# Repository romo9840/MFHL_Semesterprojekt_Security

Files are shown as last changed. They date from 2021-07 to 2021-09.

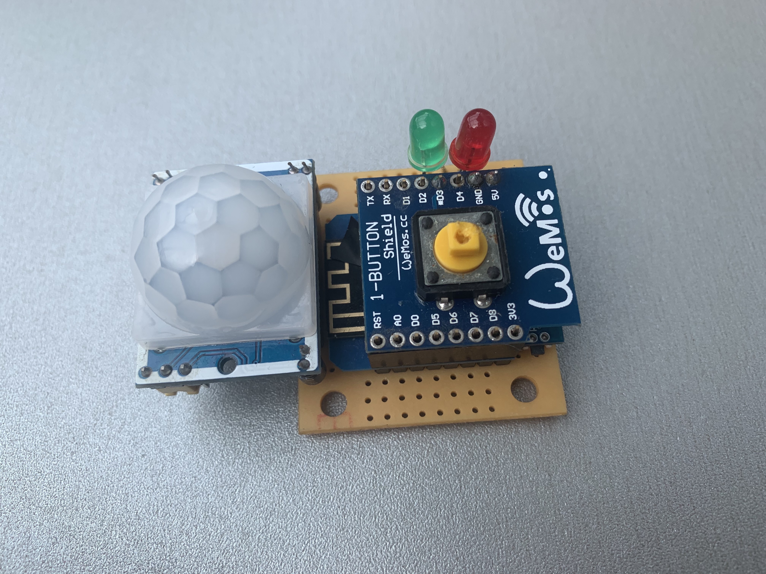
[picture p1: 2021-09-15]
Pictures/11.09_bare_other_side.jpg

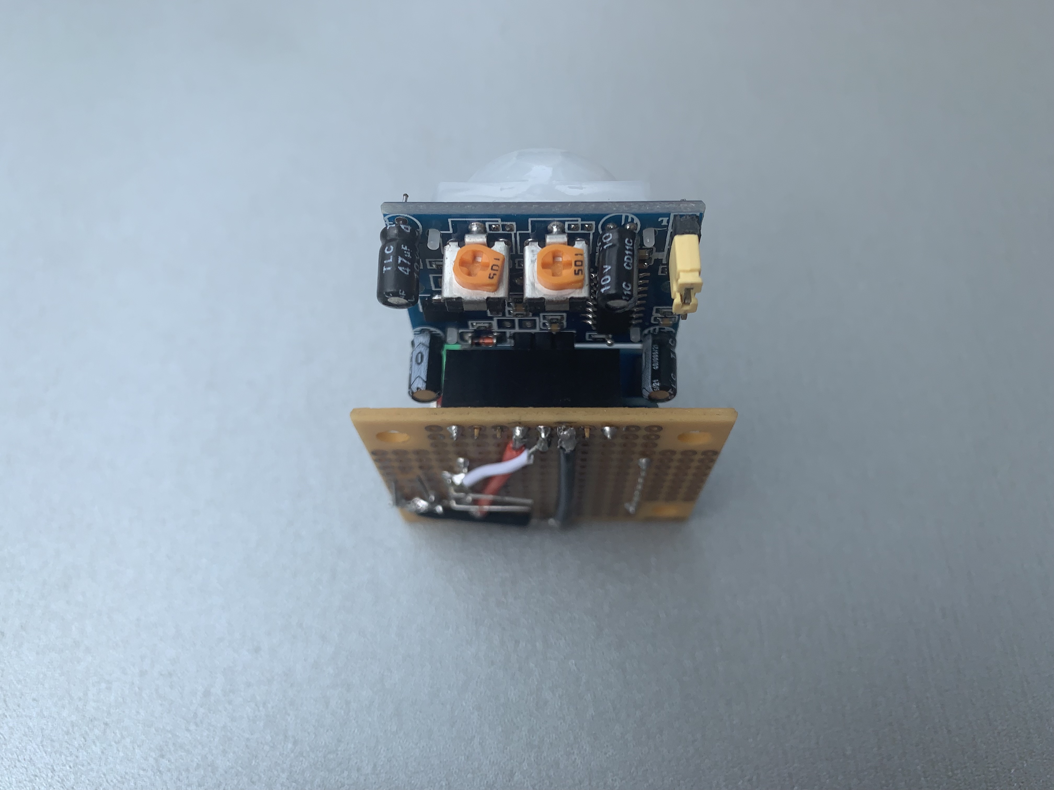
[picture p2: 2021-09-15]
Pictures/11.09_bare_back2.jpg

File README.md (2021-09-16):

# MFHL_Semesterprojekt_Security

Das hierzusehende Projekt dient dazu eine sehr einfache Sicherheitsanlage zu erschaffen. 

Collaborators: Marvin Timmerman, Felix Büntemeier, Hendrik Nessen & Leif Meyer

Hardware:
  * ESP8266 Lolin Wemos D1 Mini 
  * ~~2 Buttons~~ ESP8266 Button Shield
  * Zwei LEDs 5mm (Rot und Grün)
  * 1 Widerstand 330 Ohm 
  * Ein PIR Bewegungssensor
  * Ein Netzteil
  
  ~~Möglicherweise mit Battery:~~
   * ~~1 D1 Mini Battery Shield~~
   * ~~1 LiPo Battery~~

Software:
 * Arduino 
 * Node-RED
  
Das Sicherheitssystem muss über einen "Home" sowie "Away" Zustand verfügen.
Den Zugang zu diesen Zuständen erreicht man durch das Betätigen des integrierten Buttons.

Nach einmaligem Betätigen des Buttons wird der Zustand "Away" erreicht.
  * Die grüne LED erlischt und die rote LED permanent auf.
  * Der Timer beginnt und stoppt bei einer Dauer von 2 Minuten.
  * Nachdem der Timer abgelaufen ist, erfasst der Sensor jede Bewegung.
  * Nachdem eine Bewegung erkannt wurde, wird umgehend eine Benachrichtung an Discord sowie Email versandt.
  * Innerhalb der Zustände kann ein Wechsel ausnahmslos durch Betätigen des Buttons initiiert werden.

Das Sicherheitssystem wird im "Home" Zustand lediglich in Bereitsschaft versetzt. Hier wird nur das auf Betätigen des Buttons reagiert.
 * Die grüne LED leuchtet permanent auf.

Nach längeren Betätigung des Buttons wird der Nachtmodus aufgerufen. Dabei erlöscht die aktuelle LED.

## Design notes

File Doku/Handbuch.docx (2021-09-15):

Handbuch „Sicherheitssystem“

Inbetriebnahme:

1. Vorbereitung
  a. Arduino Code von https://github.com/romo9840/MFHL_Semesterprojekt_Security/tree/main/Software/Arduino/Securitysystem herunterladen
  b. Bibliotheken für Arduino und Paletten für Node Red einbinden
    i. Paletten: node-red-contrib-discord-advanced, node-red-node-email
    ii. Bibliotheken: https://pubsubclient.knolleary.net, https://github.com/esp8266/Arduino/tree/master/libraries/ESP8266WiFi
  c. Verbindung zwischen Box und Computer mittels Micro-USB-Kabel herstellen
  d. WiFi-Daten und MQTT-Broker anpassen (Bilder)

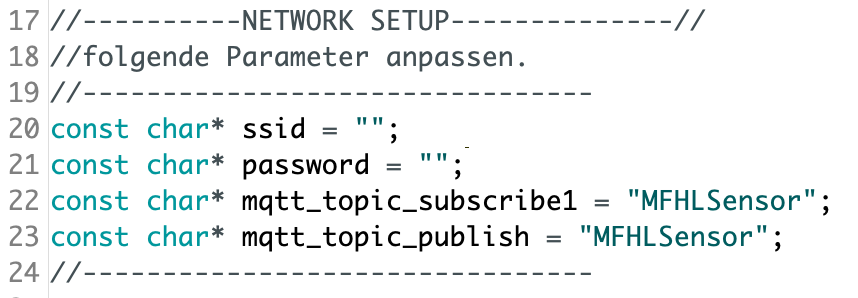
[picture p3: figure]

  e. Software auf die Security Box laden
2. Installation und Bedienung
  a. Schließen Sie das Sicherheitssystem mit dem im Lieferumfang enthaltenen Micro-USB Kabel an das Stromnetz an, um die Inbetriebnahme zu starten.
  b. Sobald das Sicherheitssystem mit dem Strom verbunden wurde, leuchtet die grüne LED auf.
  c. Das Sicherheitssystem befindet sich nun im „Home-Modus“.
  d. Durch das Betätigen des Home-Buttons wird der „Away-Modus“ aktiviert.
  e. Die rote LED leuchtet auf. Das Wechseln der Modi ist jederzeit durch Betätigen des Home-Buttons möglich.
  f. Das Sicherheitssystem ist nun einsatzbereit.
3. Installation des Benachrichtigungssystems
  a. 2.1 Email-Benachrichtigung
    i. Um vom Benachrichtigungssystem entsprechende Warnmeldungen zu erhalten, muss eine Verbindung zum Email- sowie Discord-Server hergestellt werden.

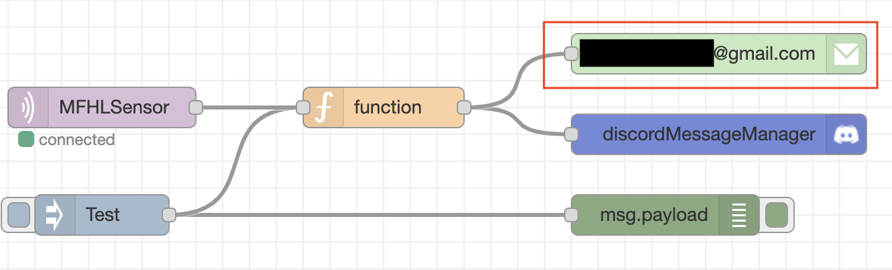
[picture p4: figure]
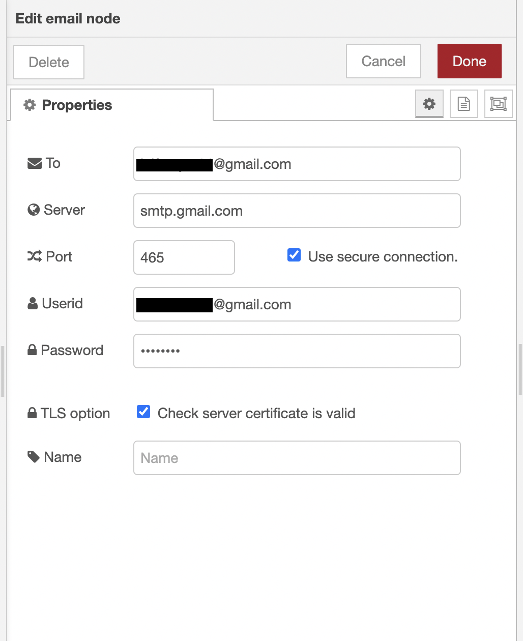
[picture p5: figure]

    ii. Verwenden sie die Email-App ihres Mobiltelefons oder eines Heimrechners um Ihre Wunschadresse für eine Benachrichtigung zu versenden
  b. 2.2 Discord-Benachrichtigung (wenn gewünscht):
    i. Um sich mit dem Sicherheitsserver zu verbinden, laden Sie die benötigte Software „Discord“ unter der Webseite (www.Discord.de) herunter.
    ii. Nach erfolgreicher Installation können Sie den Sicherheitsserver hinzufügen, indem sie auf die Schaltfläche „Server hinzufügen“ klicken.
    iii. Navigieren Sie anschließend zu der Schaltfläche „Tritt einem Server bei“.
    iv. Nach Eingabe des Einladungslinks (abcdef.ff.f) betreten Sie den Sicherheitsserver.
    v. Das Benachrichtigungssystem ist nun einsatzbereit.

Home-Modus: In diesem Zustand reagiert das Sicherheitssystem auf keine Bewegung.

Vorzugsweise sollte dieser Modus aktiviert werden, wenn Sie sich zu Hause befinden.

BILD

Away-Modus: Nach einer Sicherheitsdauer von 2 Minuten wird die Bewegungserfassung des Sicherheitssystems aktiviert.

Sollte das Sicherheitssystem eine Bewegung erkennen, wird eine Warnmeldung durch das Benachrichtigungssystem eingeleitet.

BILD

Known-Issues:

Interne LED des Wemos D1 mini wird über PIN D4 gesteuert, deswegen kann diese auch leuchten

Videomaterial zur Inbetriebnahme:

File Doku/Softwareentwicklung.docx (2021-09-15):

Beschreibung der Systemarchitektur und der Softwareentwicklung

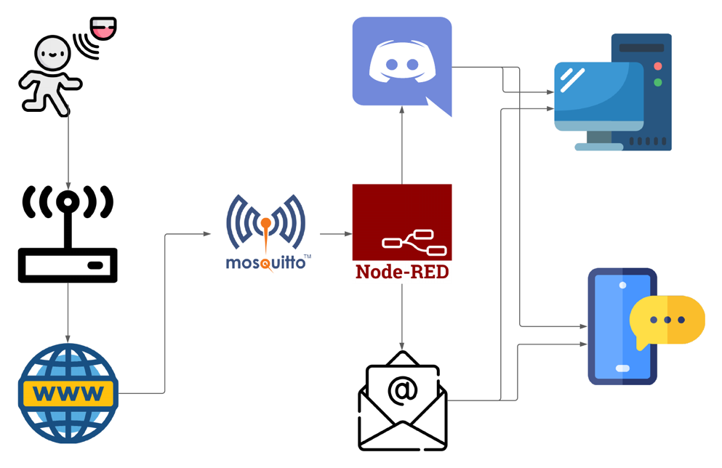
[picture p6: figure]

Abbildung 1/ Systemübersicht

Das Sicherheitssystem stellt bei Inbetriebnahme eine Verbindung zu einem spezifizierten Netzwerk her. Dies ist notwendig, um eine Kommunikation zwischen den Systemen zu gewährleisten. Erkennt das Sicherheitssystem eine Bewegung, wird eine entsprechende Meldung via MQTT über das Internet übermittelt. Die Daten werden von einem Broker (Mosquitto) empfangen und an einen Node-RED Server weitergeleitet.

Die empfangenen Daten werden mittels Node-RED als Email-, sowie Discord-Nachricht verarbeitet und weitergeleitet. Die verarbeitete Meldung erscheint schließlich auf den jeweiligen Endgeräten.

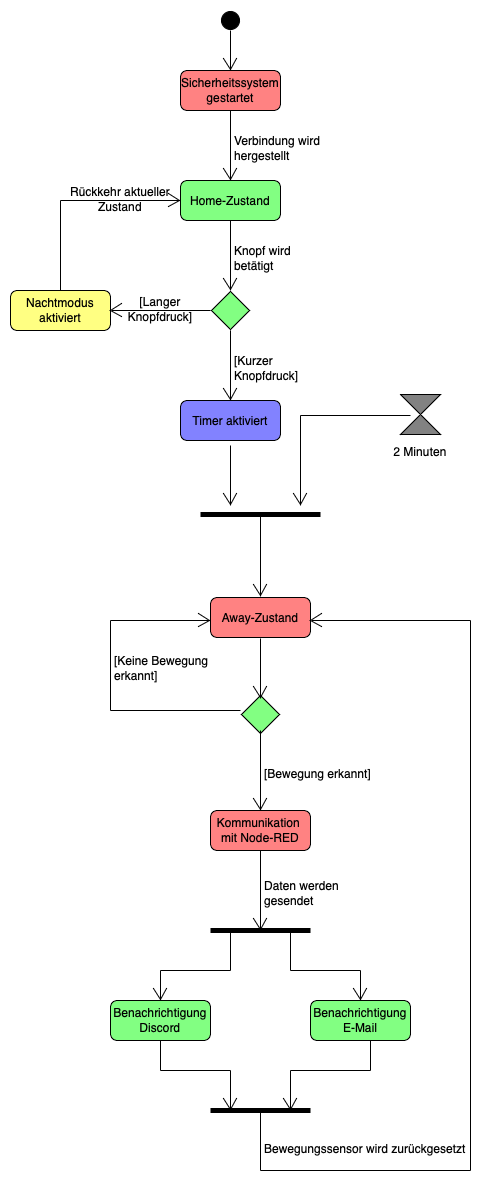
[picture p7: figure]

Abbildung2/ Zustandsdiagramm

Bei Start des Sicherheitssystems wird beginnend das Setup des Programms ausgeführt. In dieser Phase werden Verbindungen zum Netzwerk, zum MQTT-Broker sowie zum Node-RED Client hergestellt und aufrechterhalten.

Nachdem alle Verbindungen erfolgreich hergestellt werden konnten, beginnt die „Loop-Methode“ des Programms. In diesem Teil des Programms wird die Logik des Buttons und des Sicherheitssystems umgesetzt.

Die von Spivey entwickelte Button-Logik nutzt Zustände und Timer, um zwischen kurzen und langen Tastendrücken zu unterscheiden. Dies ist für die spezifische Funktionalität des Sicherheitssystems notwendig. Erkennt das System einen kurzen Knopfdruck, wechselt das System abhängig vom vorherigen Zustand in den „Home“- oder den „Away“-Zustand. Registriert das System einen langen Knopfdruck, wird der Nachtmodus des Sicherheitssystems aktiviert. Die LED-Leuchten werden deaktiviert und der aktuelle Zustand bleibt bestehen.

Das eingeschaltete System befindet sich im Ausgangszustand „Home“. In diesem Zustand wird lediglich die grüne LED-Leuchte aktiviert. Es werden in diesem Zustand keine Bewegungsdaten erfasst und ausgewertet.

Nachdem das System in den „Away“ -Zustand gelangt, erlischt die grüne LED-Leuchte und die rote LED wird aktiviert. Mithilfe eines im Setup definierten Zählers „counter“, kann zwischen Zuständen vor und nach der Timerlogik separiert werden. Dabei wird bei erstmaligem Eintritt in den „Away“-Zustand durch den vordefinierten Zähler das Sicherheitszeitintervall von zwei Minuten gestartet. Nachdem der Timer abgelaufen ist, gelangt man durch das Inkrementieren des Zählers in den Folgezustand, welcher die Bewegungssensorik aktiviert.

Erkennt das Sicherheitssystem eine Bewegung, wird eine entsprechende Meldung an den MQTT-Broker übermittelt. Nach einer kurzen Verzögerung wird der Zähler wieder zurückgesetzt und das Programm gelangt wieder in den Zustand, welcher für die Bewegungserkennung verantwortlich ist. So kann eine Überwachung ohne erneute Einhaltung des Sicherheitszeitintervalls gewährleistet werden.

Die Datenübertragung wird über einen mit Node-RED eingerichteten Server abgewickelt. Innerhalb des Programms wird ein vordefiniertes Topic („MFHLSensor“) genutzt, um eine Kommunikation über den MQTT Broker zu ermöglichen. Bei eintretender Bewegungserkennung wird mit der „publishString“ Methode eine Kommunikation zwischen den Schnittstellen eingeleitet. Nachdem die Daten an Node-RED übermittelt worden sind, muss eine Weiterleitung an die entsprechenden Endgeräte stattfinden.

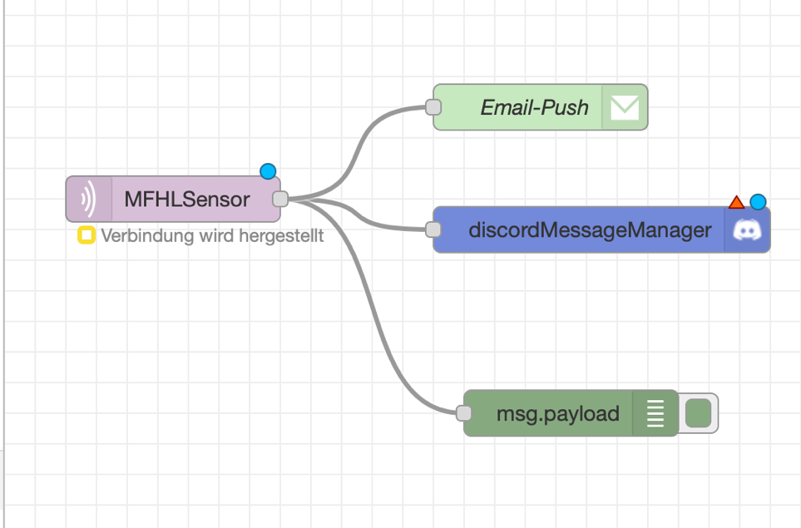
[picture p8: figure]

Abbildung 3/ Node-RED Konfiguration

Über das Netzwerk-Node „mqtt-in“ kann durch das Festlegen eines vorspezifizierten Servers, sowie Topics ein Dateninput verarbeitet werden. Dabei werden die Nodes „discord“ und „email“ zur Weiterleitung einer Push-Benachrichtigung genutzt.

Um eine Push-Benachrichtung an eine E-Mail Adresse weiterzuleiten, muss das „email“ Node lediglich mit Server, Port und den ID-Daten des Nutzers synchronisiert werden.

Um eine Push-Benachrichtigung via Discord-Bot durchzuführen, muss eine Applikation, sowie ein Discord-Bot initialisiert werden. Über das Developer-Portal von Discord kann eine entsprechende Applikation erstellt werden, welche das Verwenden eines Discord-Bots ermöglicht.

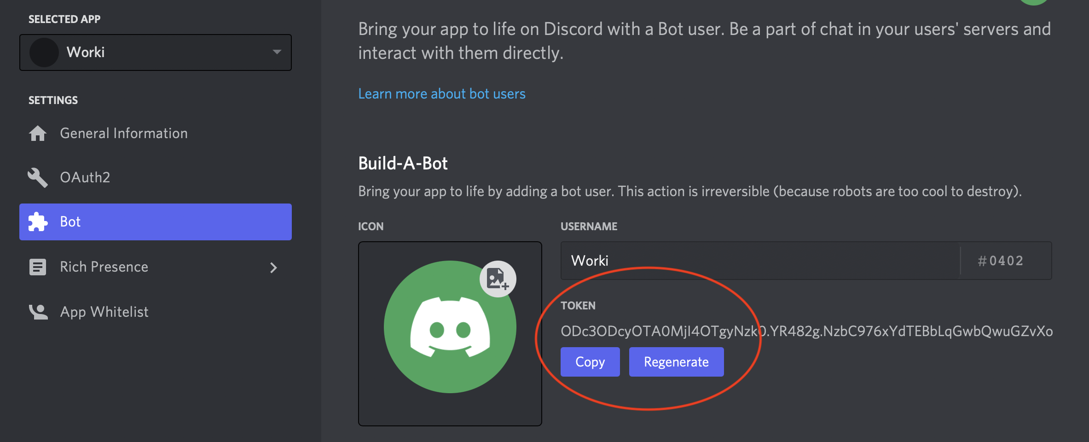
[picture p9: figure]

Abbildung 4/ Discord Developer Portal

Der erstellte Discord-Bot wird mit einem gegebenen Token über Node-RED initialisiert. So kann eine Kommunikation zwischen den Systemen stattfinden und eine Meldung an die Endgeräte weitergeleitet werden.

Code & Bibliotheken

Probleme bei der Software-Entwicklung:

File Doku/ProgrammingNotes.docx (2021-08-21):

# Node-Red Setup

### Email: ( node-red-node-email )

Um eine E-Mail mit Nodered zu verbinden ist es empfohlen eine gmail zu verwenden. Sonst ist es auch möglich andere E-mail Konten zu verbinden falls die entsprechenden Daten (Server, Port, Userid und Passwort) bekannt sind.

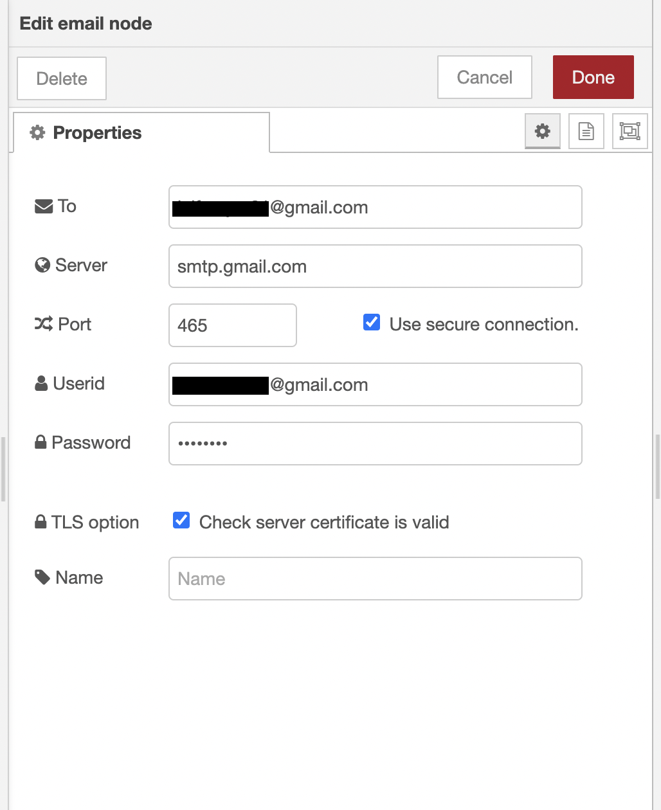
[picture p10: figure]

Hier ist die Dokumentation des Email-Nodes zu sehen:

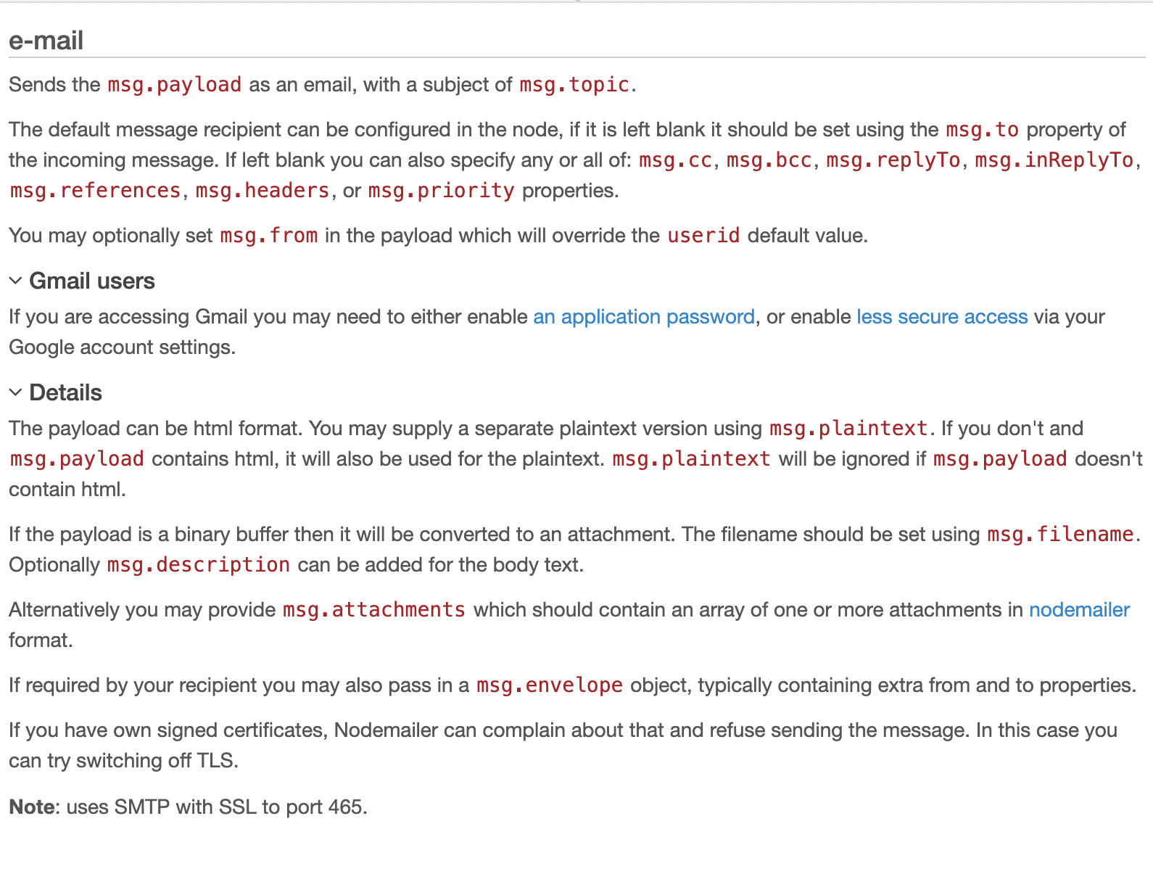
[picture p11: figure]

### Discord: ( node-red-contrib-discord-advanced )

Zuerst wird ein Discord-Bot erstellt. Dafür folgt man den folgenden Link, um die Discord Developer Seite zu erreichen https://discord.com/developers/applications. Nach den einloggen kann es sein, dass erneut den Link eingeben muss.

Zunächst ist eine Applikation sowie ein Bot in dieser Applikation zu erstellen. Dann muss der Bot mit einem Server verbunden werden. Der Bot wird mittels der OAuth2 Funktion einen Server ihrer Wahl zugewiesen (dafür muss aber ein Server schon erstellt sein). Die Attribute des Bots werden hier auch ausgesucht.

Hier wird als SCOPES:={bot} und BOT PERMISSIONS:={Send Messages} ausgewaehlt.

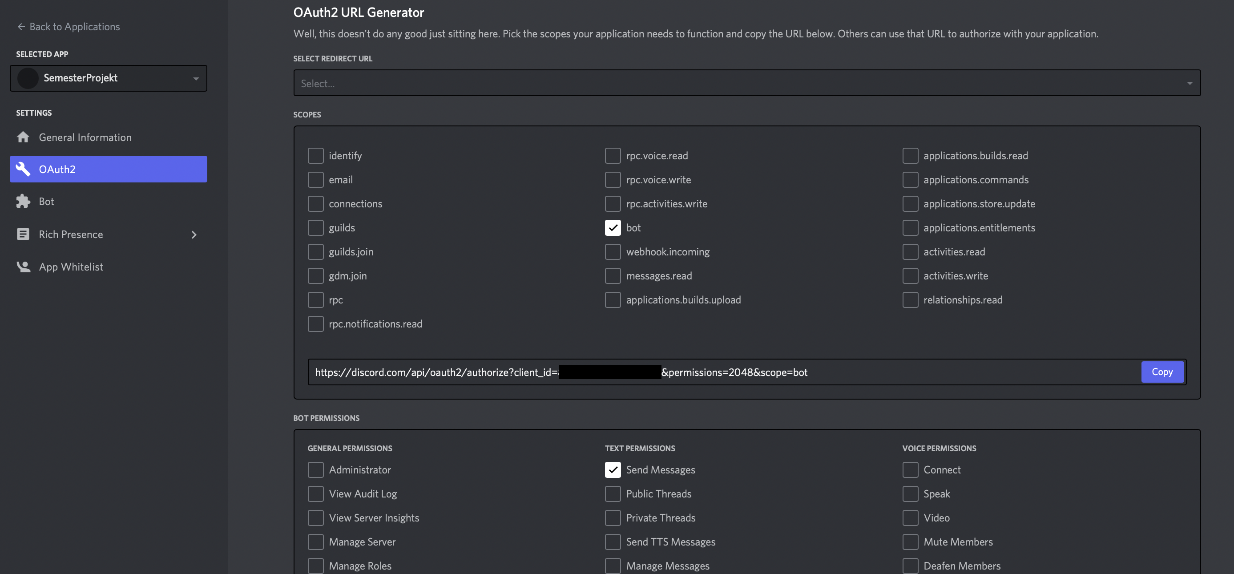
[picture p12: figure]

Der Link muss hier kopiert und in dem Browser eingefügt werden. Danach wird nach dem Server gefragt, der diesen Bot empfangen soll. Dies schließt das Setup von Discord aus ab.

#### Node Red:

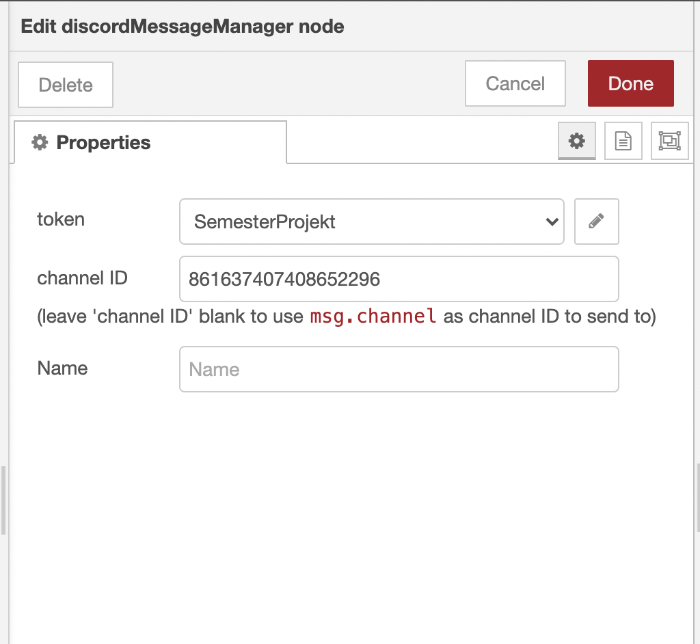
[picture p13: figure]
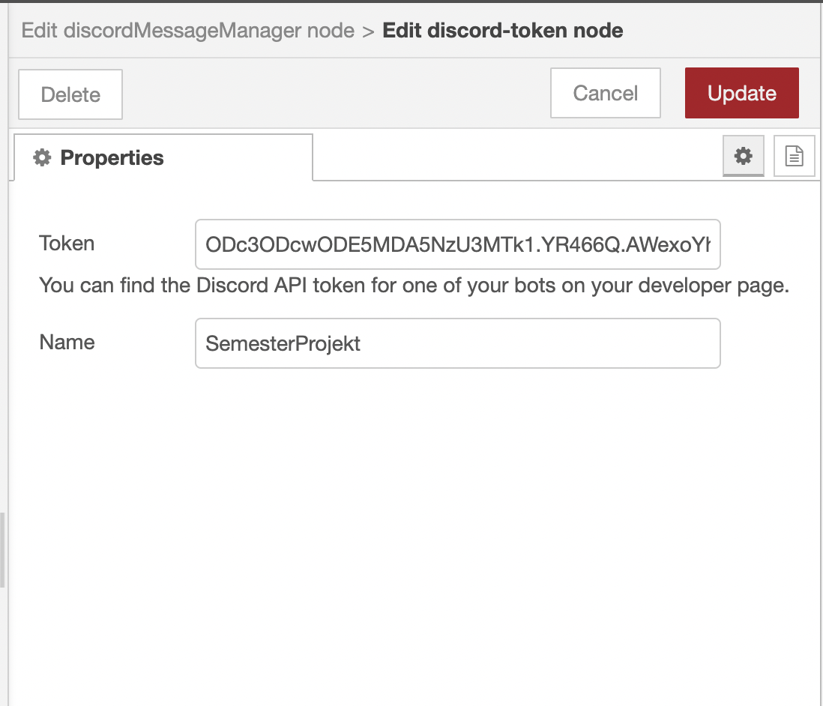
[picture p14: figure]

Die Channel_ID wird gefunden falls man in der Discord App

> Settings > App Settings > Advanced > Developer Mode enabled und dann beim Server die mit Rechtsklick auf die ID vom gewählten Channel kopiert.

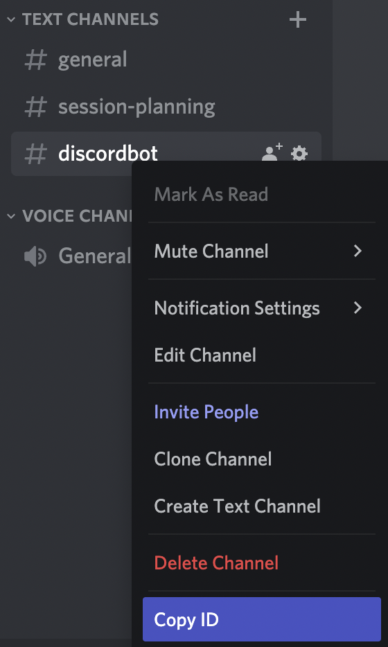
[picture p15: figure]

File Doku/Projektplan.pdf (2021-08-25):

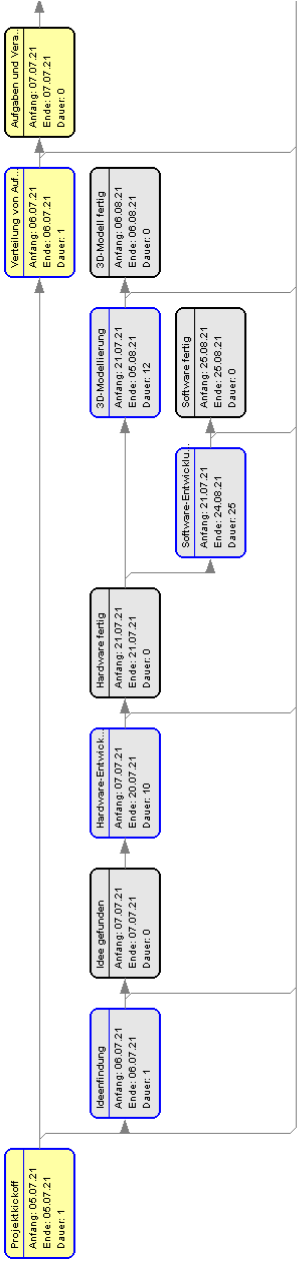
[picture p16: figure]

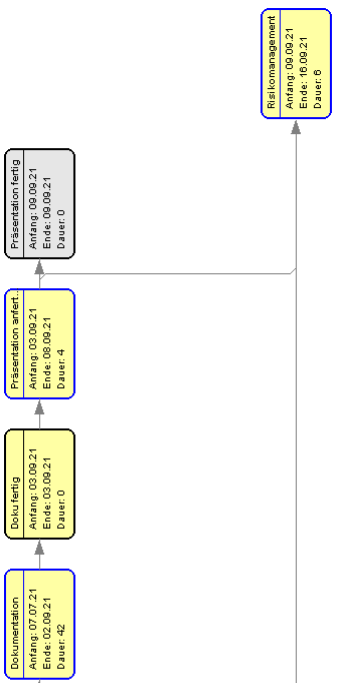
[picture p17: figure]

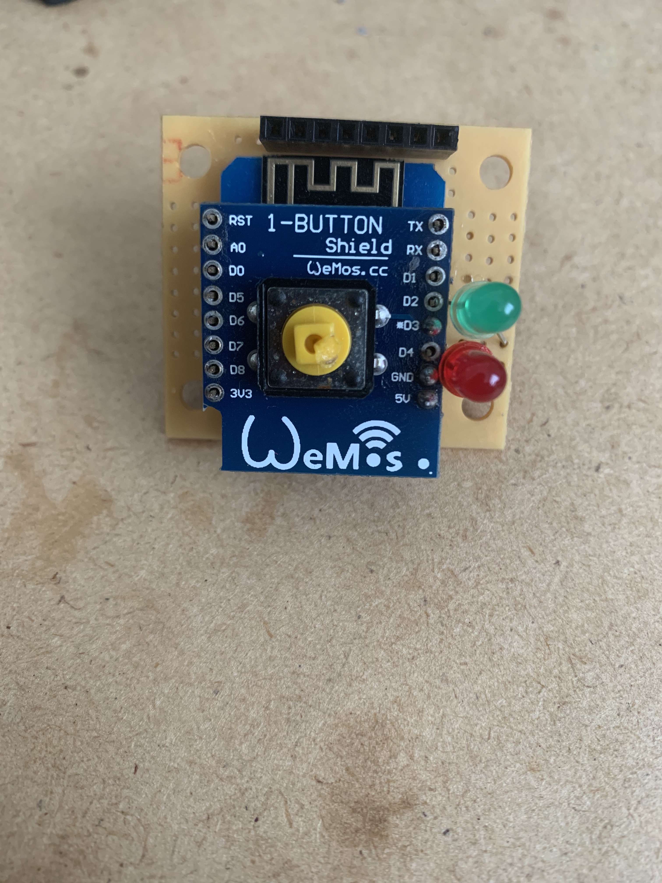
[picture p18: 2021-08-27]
Pictures/22.07_Top.jpg

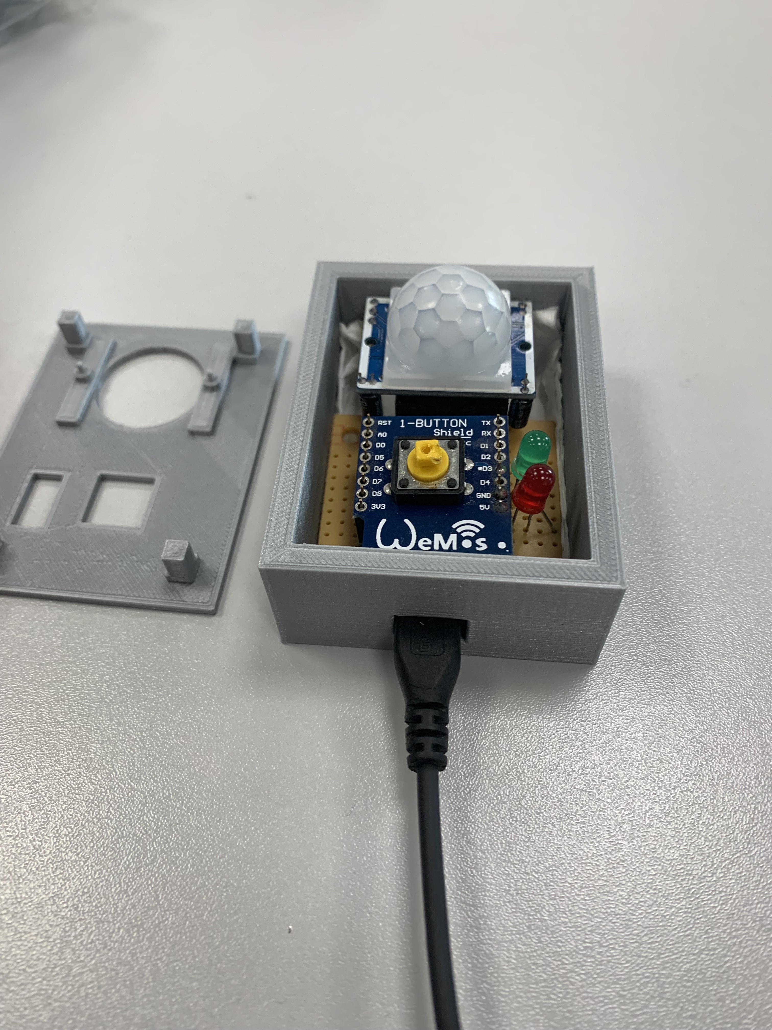
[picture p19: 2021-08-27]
Pictures/19.08_Inside_Bottom.jpg

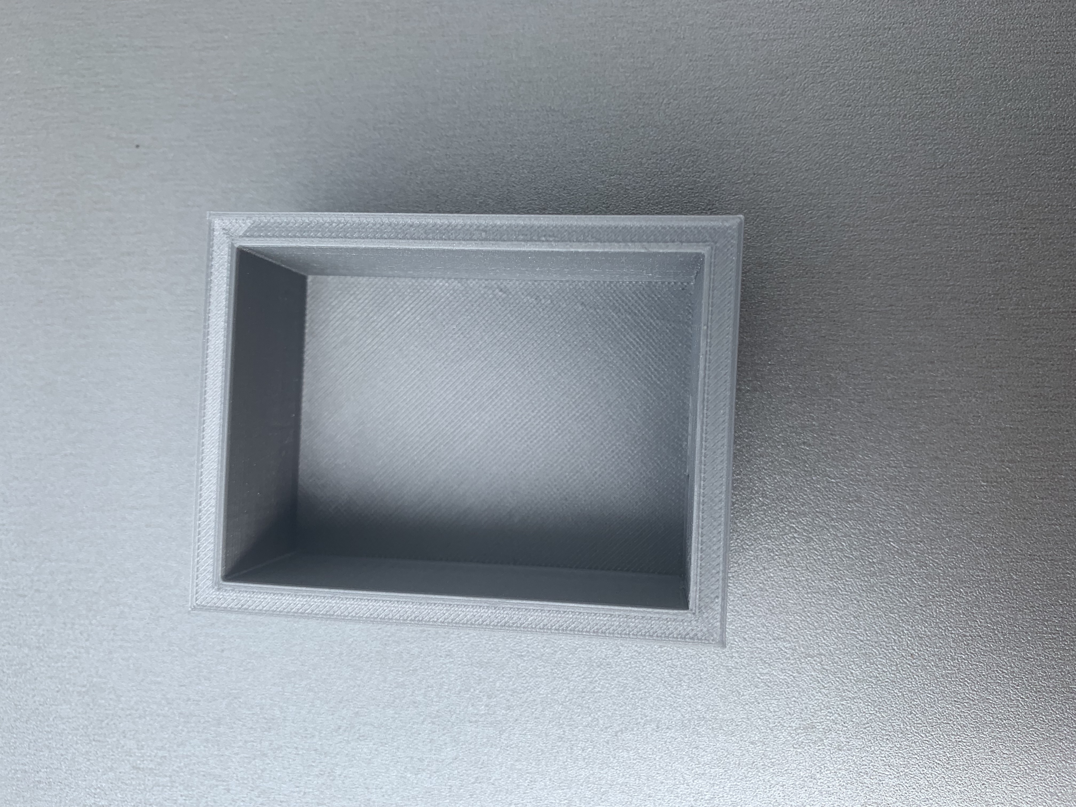
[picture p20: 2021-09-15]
Pictures/11.09_case.jpg

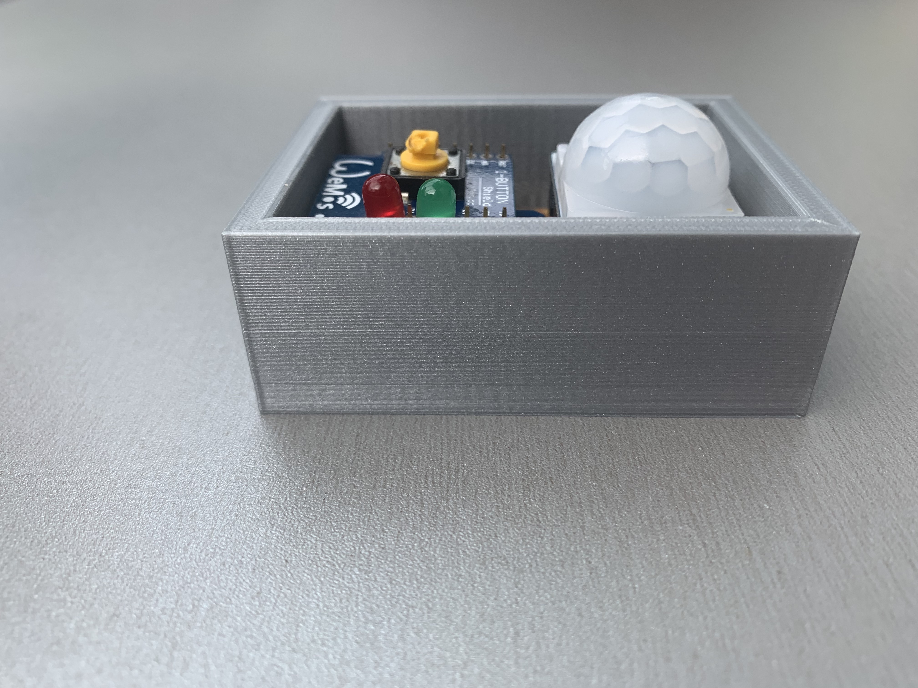
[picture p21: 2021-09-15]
Pictures/11.09_open_side.jpg

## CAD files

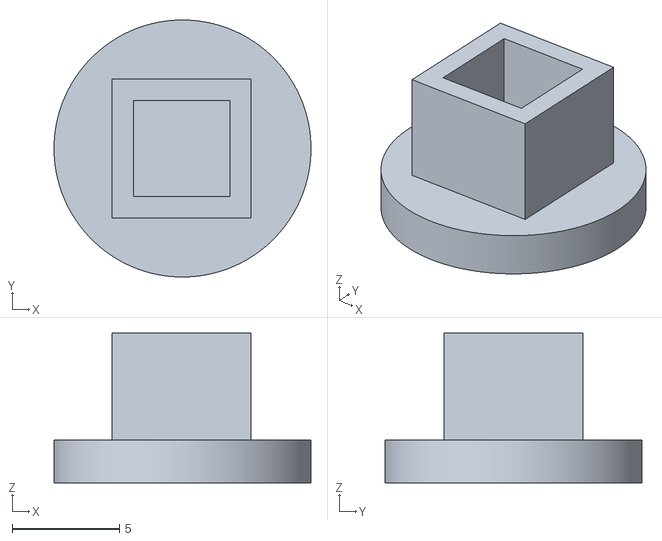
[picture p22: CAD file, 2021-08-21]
3D_Modelle/Security_Box_Button_V2.stl
12.0 x 12.0 x 7.00

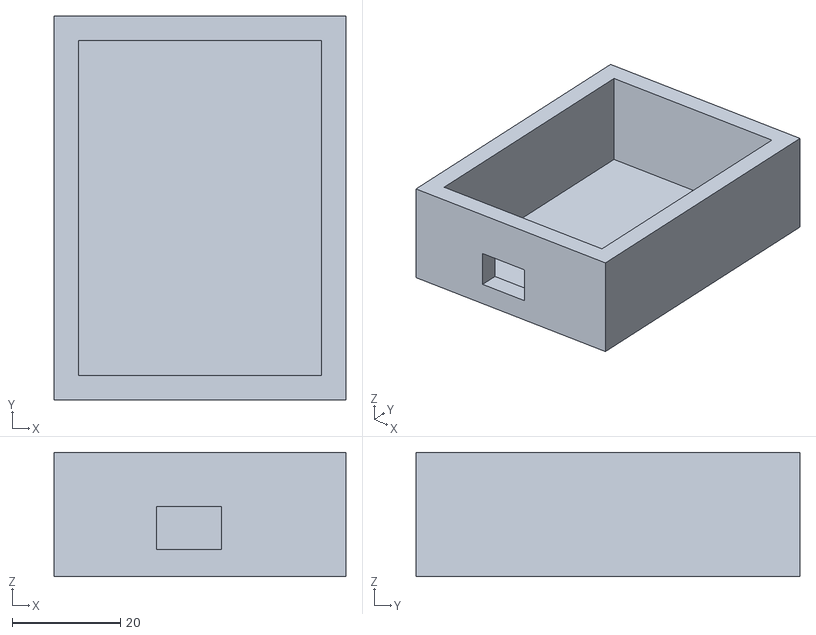
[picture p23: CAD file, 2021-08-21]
3D_Modelle/Security_Box_Koerper_V2.stl
54.0 x 71.0 x 23.0

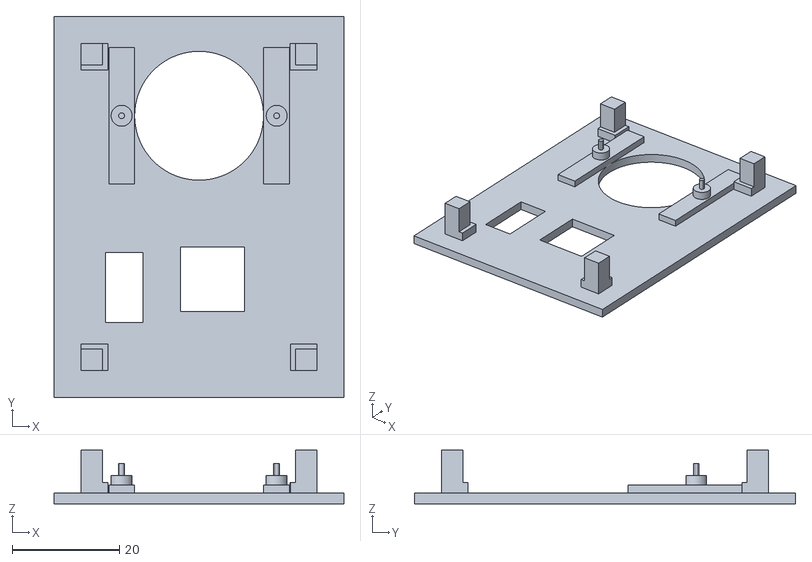
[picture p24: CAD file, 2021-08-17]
3D_Modelle/Security_Box_Deckel_V2.stl
54.0 x 71.0 x 10.0

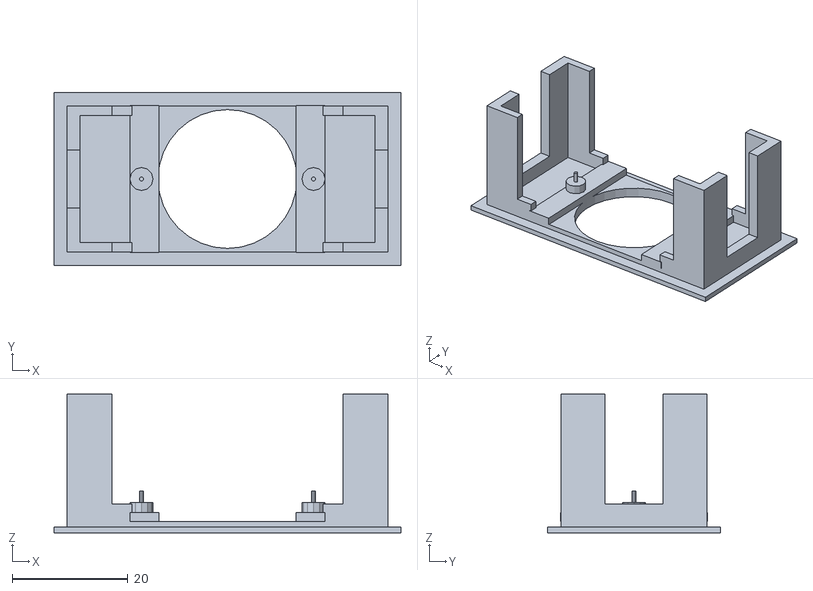
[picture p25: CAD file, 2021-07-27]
3D_Modelle/lid_PIR.stl
60.0 x 30.0 x 24.0

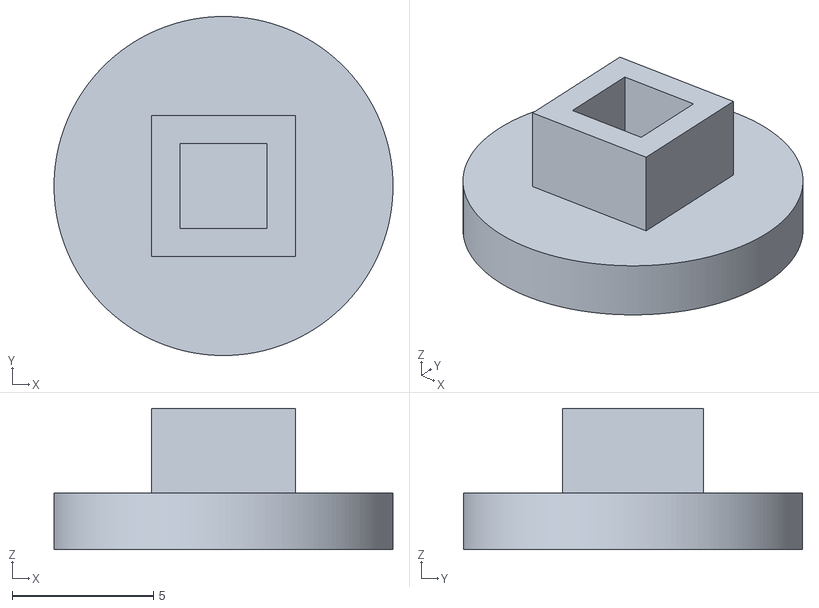
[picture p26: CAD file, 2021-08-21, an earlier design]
3D_Modelle/Security_Box_Button_V1.stl
12.0 x 12.0 x 5.00

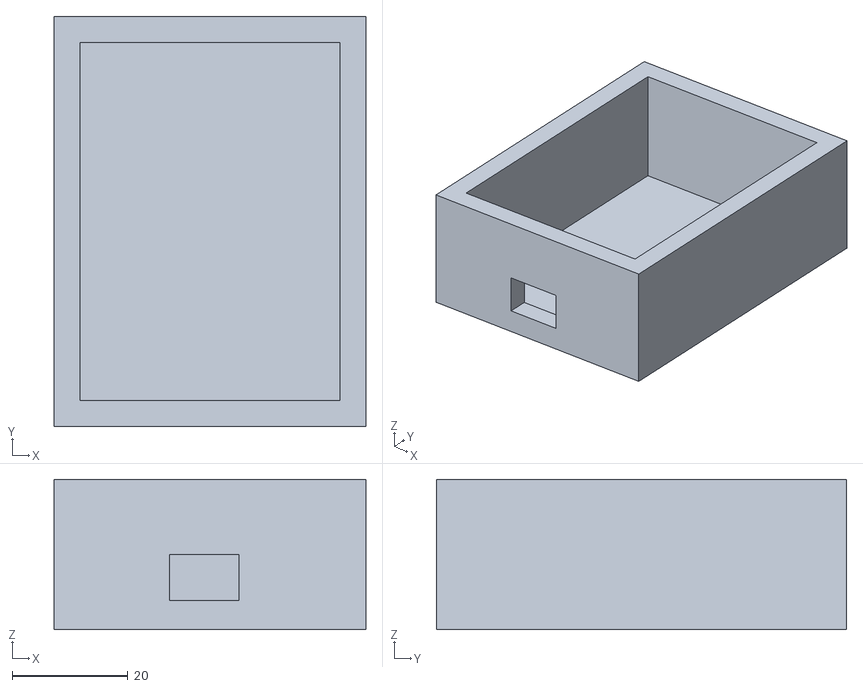
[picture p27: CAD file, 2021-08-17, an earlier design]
3D_Modelle/Security_Box_Koerper_V1.stl
54.0 x 71.0 x 26.0

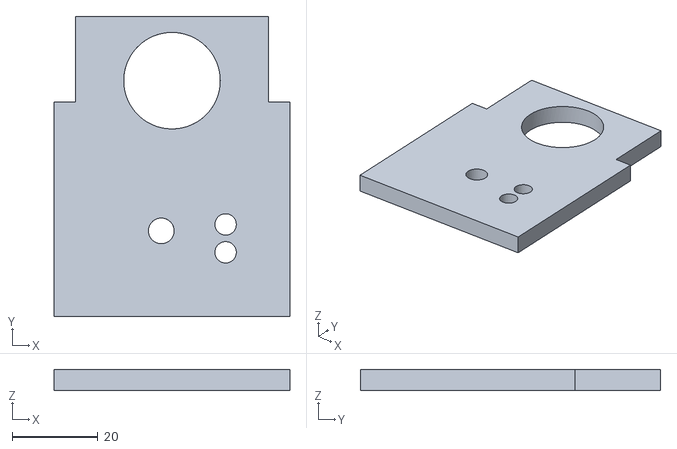
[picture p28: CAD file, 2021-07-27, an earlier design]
3D_Modelle/Security_Box_Deckel_V1.stl
55.0 x 70.0 x 5.00

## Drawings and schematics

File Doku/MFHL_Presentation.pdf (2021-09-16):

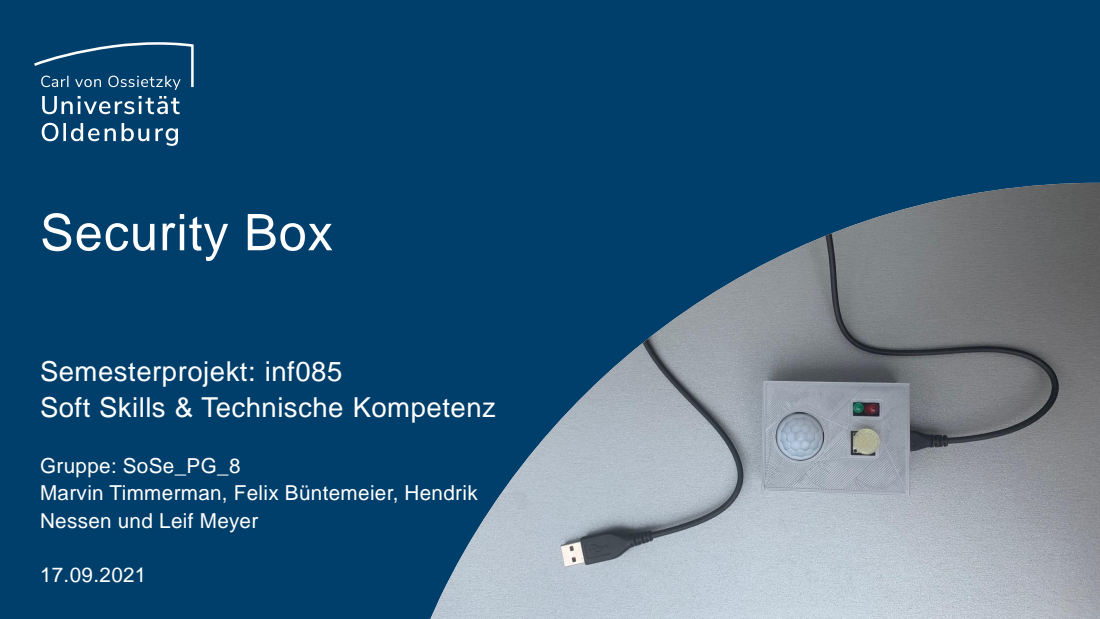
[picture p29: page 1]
Security Box

Semesterprojekt: inf085
Soft Skills & Technische Kompetenz

Gruppe: SoSe_PG_8
Marvin Timmerman, Felix Büntemeier, Hendrik
Nessen und Leif Meyer

## Gliederung

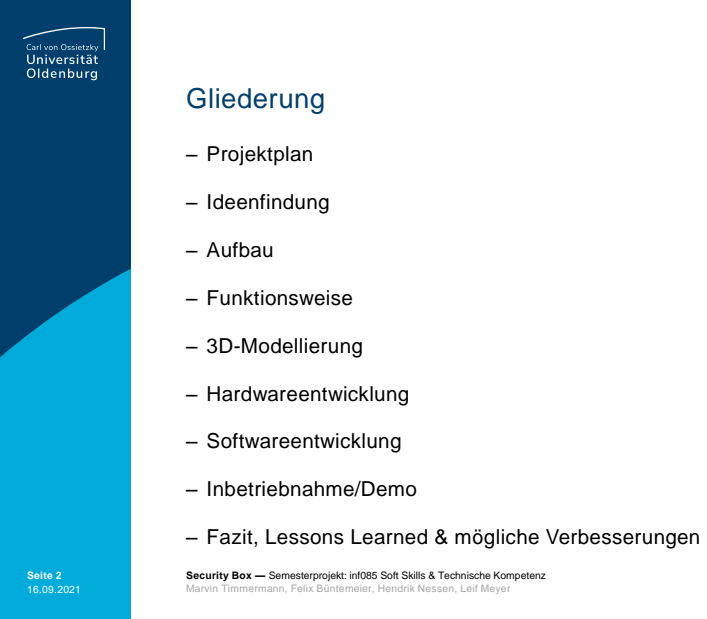
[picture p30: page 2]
Seite 2; Security Box — Semesterprojekt: inf085 Soft Skills & Technische Kompetenz; Marvin Timmermann, Felix Büntemeier, Hendrik Nessen, Leif Meyer; ‒ Projektplan; ‒ Ideenfindung; ‒ Aufbau; ‒ Funktionsweise; ‒ 3D-Modellierung; ‒ Hardwareentwicklung; ‒ Softwareentwicklung; ‒ Inbetriebnahme/Demo

‒ Fazit, Lessons Learned & mögliche Verbesserungen

## Projektplan

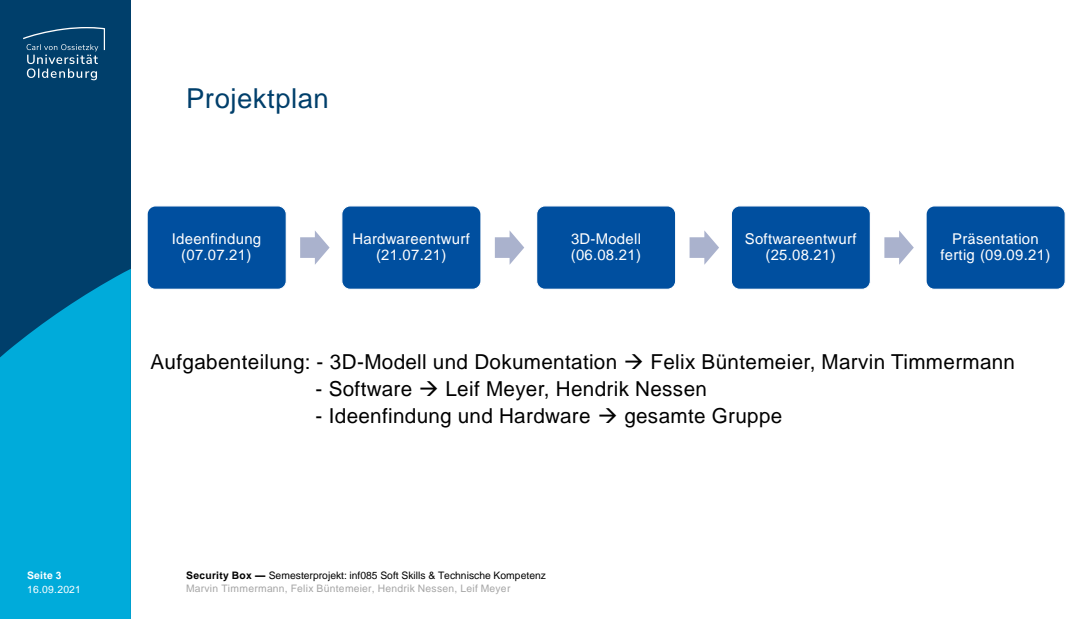
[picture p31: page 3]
Seite 3; Security Box — Semesterprojekt: inf085 Soft Skills & Technische Kompetenz; Ideenfindung (07.07.21); Hardwareentwurf (21.07.21); 3D-Modell (06.08.21); Softwareentwurf (25.08.21); Präsentation fertig (09.09.21)

Aufgabenteilung: - 3D-Modell und Dokumentation → Felix Büntemeier, Marvin Timmermann

- Software → Leif Meyer, Hendrik Nessen
- Ideenfindung und Hardware → gesamte Gruppe

## Ideenfindung

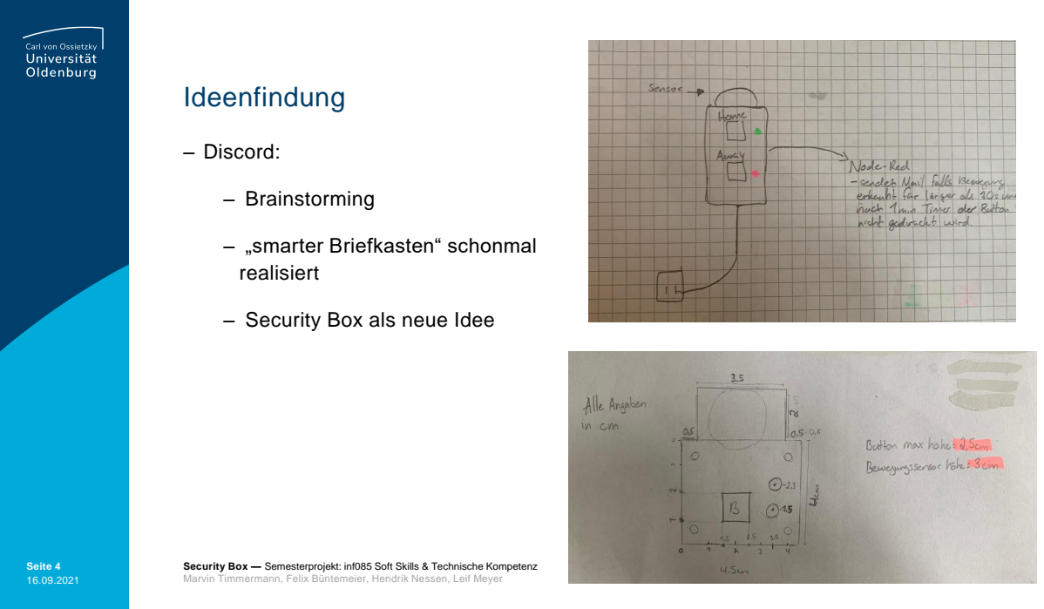
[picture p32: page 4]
Seite 4; Security Box — Semesterprojekt: inf085 Soft Skills & Technische Kompetenz; ‒ Discord:; ‒ Brainstorming

‒ „smarter Briefkasten“ schonmal
realisiert

‒ Security Box als neue Idee

## Aufbau

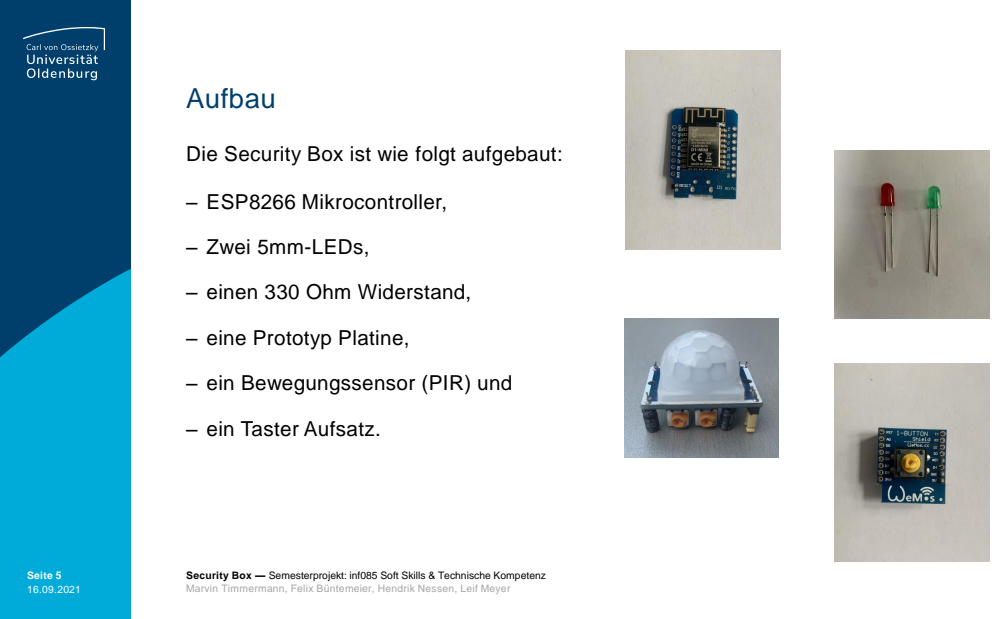
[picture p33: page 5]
Seite 5; Security Box — Semesterprojekt: inf085 Soft Skills & Technische Kompetenz; ‒ ESP8266 Mikrocontroller,; ‒ Zwei 5mm-LEDs,

Die Security Box ist wie folgt aufgebaut:

‒ einen 330 Ohm Widerstand,

‒ eine Prototyp Platine,

‒ ein Bewegungssensor (PIR) und

‒ ein Taster Aufsatz.

## Funktionsweise

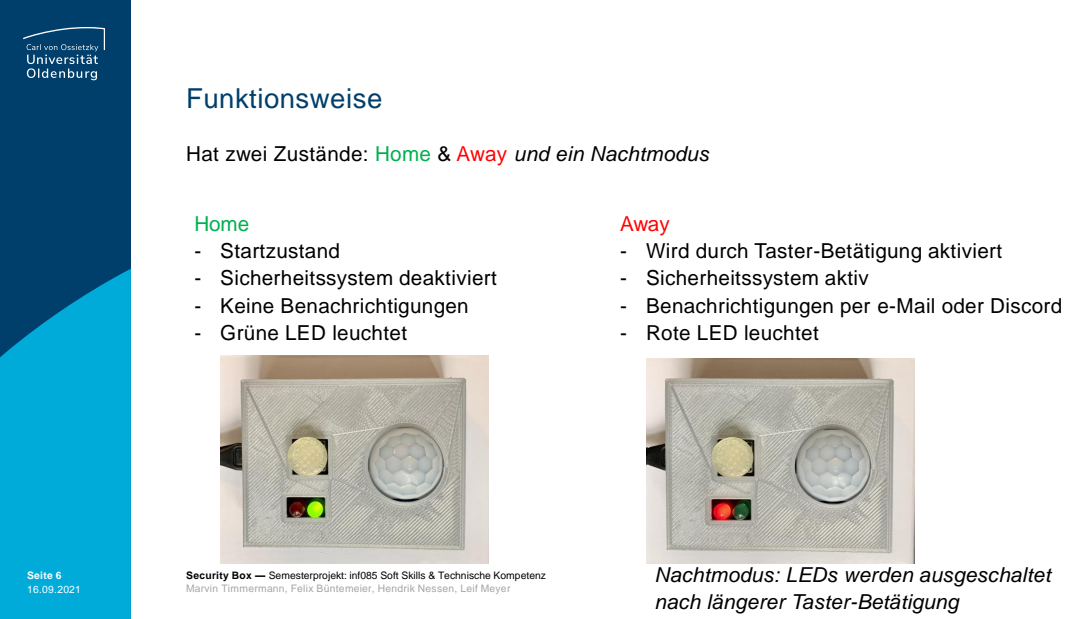
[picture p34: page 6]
Seite 6; Security Box — Semesterprojekt: inf085 Soft Skills & Technische Kompetenz

Hat zwei Zustände: Home & Away und ein Nachtmodus

Home
- Startzustand
- Sicherheitssystem deaktiviert
- Keine Benachrichtigungen
- Grüne LED leuchtet

Away
- Wird durch Taster-Betätigung aktiviert
- Sicherheitssystem aktiv
- Benachrichtigungen per e-Mail oder Discord
- Rote LED leuchtet

Nachtmodus: LEDs werden ausgeschaltet
nach längerer Taster-Betätigung

## 3D Modellierung

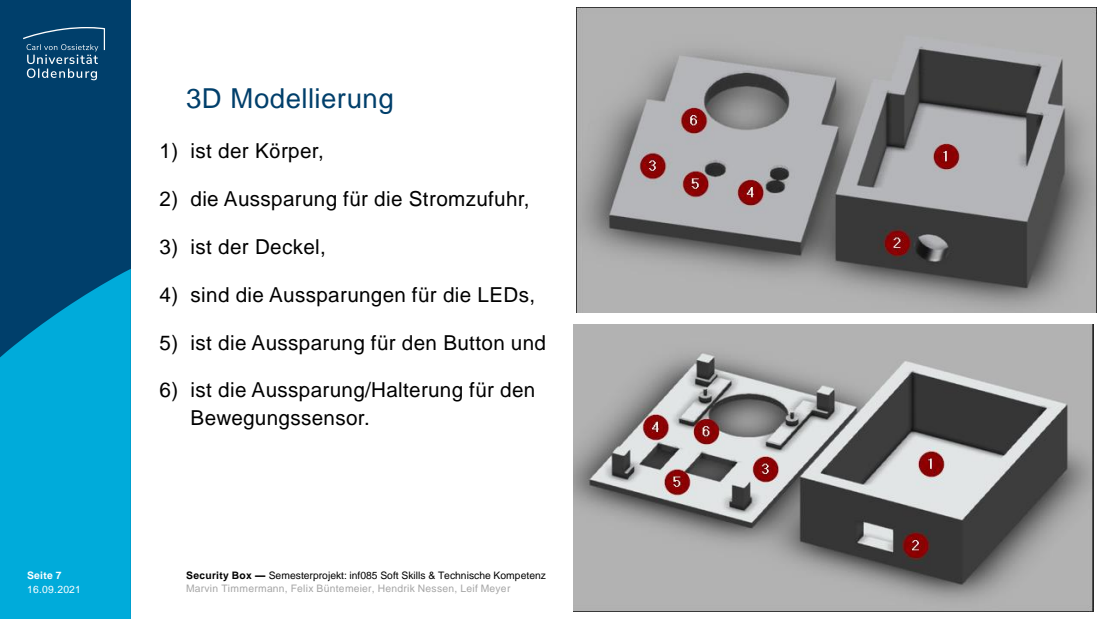
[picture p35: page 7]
Seite 7; Security Box — Semesterprojekt: inf085 Soft Skills & Technische Kompetenz

1) ist der Körper,

2) die Aussparung für die Stromzufuhr,

3) ist der Deckel,

4) sind die Aussparungen für die LEDs,

5) ist die Aussparung für den Button und

6) ist die Aussparung/Halterung für den
Bewegungssensor.

## Fertige Modelle

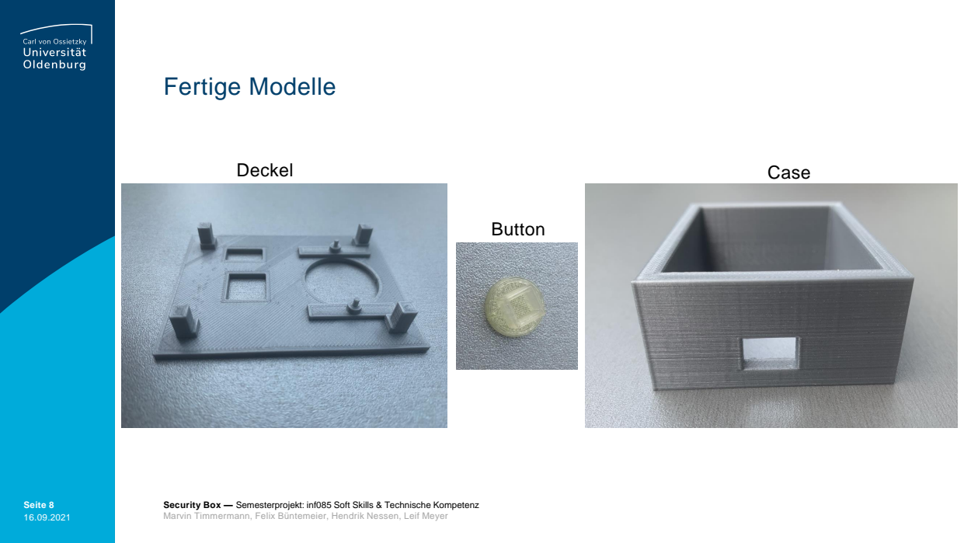
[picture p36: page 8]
Seite 8; Security Box — Semesterprojekt: inf085 Soft Skills & Technische Kompetenz; Deckel; Button; Case

## Hardwareentwicklung

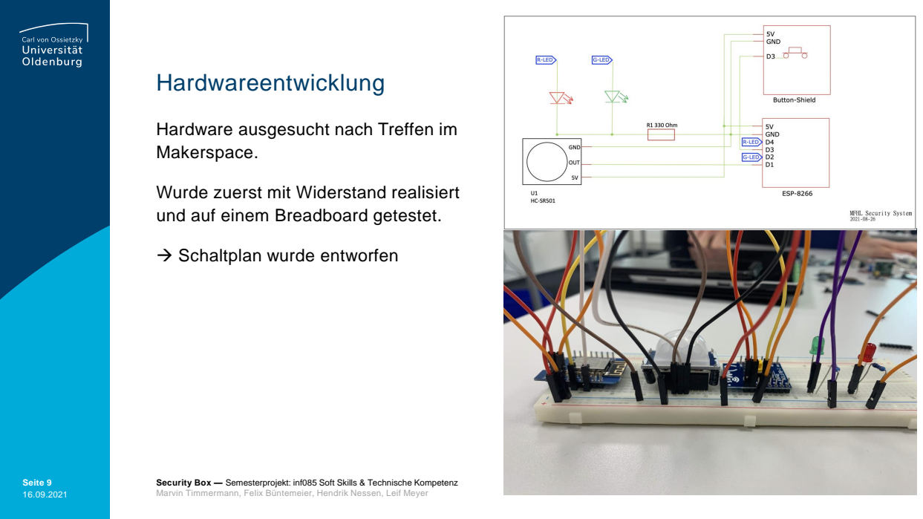
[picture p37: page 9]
Seite 9; Security Box — Semesterprojekt: inf085 Soft Skills & Technische Kompetenz

Hardware ausgesucht nach Treffen im
Makerspace.

Wurde zuerst mit Widerstand realisiert
und auf einem Breadboard getestet.

→ Schaltplan wurde entworfen

## Hardwareentwicklung

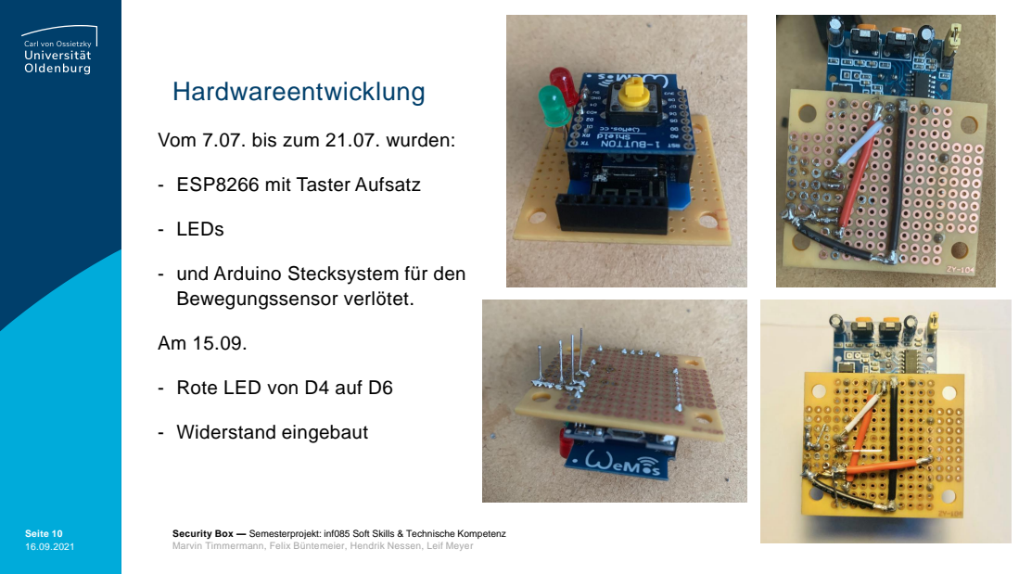
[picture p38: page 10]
Seite 10; Security Box — Semesterprojekt: inf085 Soft Skills & Technische Kompetenz; - LEDs; - Widerstand eingebaut

Vom 7.07. bis zum 21.07. wurden:

- ESP8266 mit Taster Aufsatz

- und Arduino Stecksystem für den
Bewegungssensor verlötet.

- Rote LED von D4 auf D6

## Probleme bei der Hardwareentwicklung

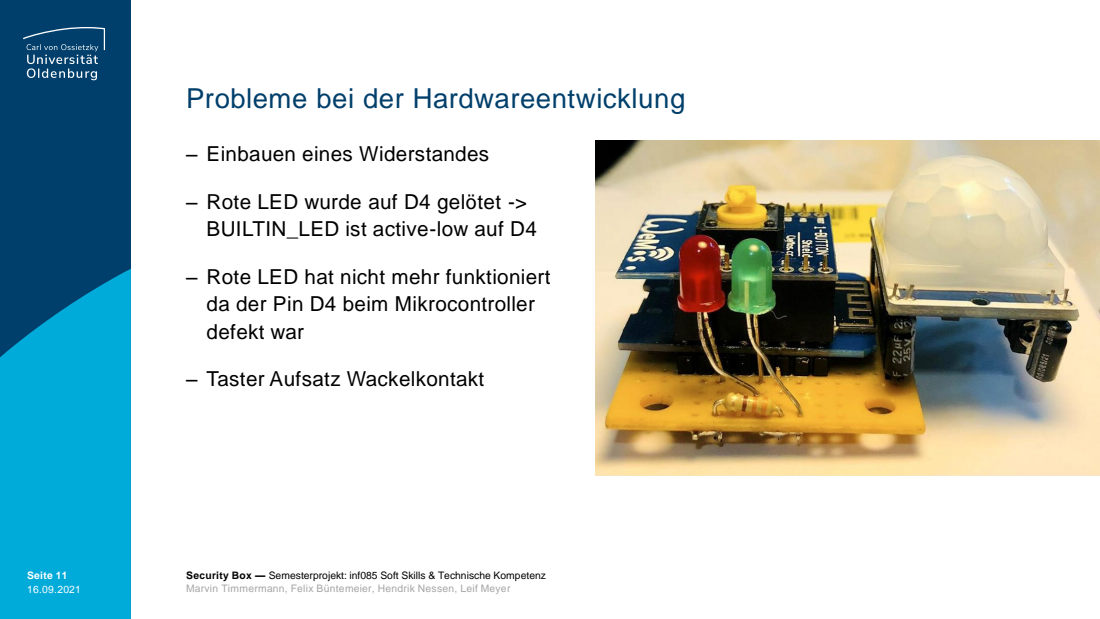
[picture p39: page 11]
Seite 11; Security Box — Semesterprojekt: inf085 Soft Skills & Technische Kompetenz

‒ Einbauen eines Widerstandes

‒ Rote LED wurde auf D4 gelötet ->
BUILTIN_LED ist active-low auf D4

‒ Rote LED hat nicht mehr funktioniert
da der Pin D4 beim Mikrocontroller
defekt war

‒ Taster Aufsatz Wackelkontakt

## Softwareentwicklung

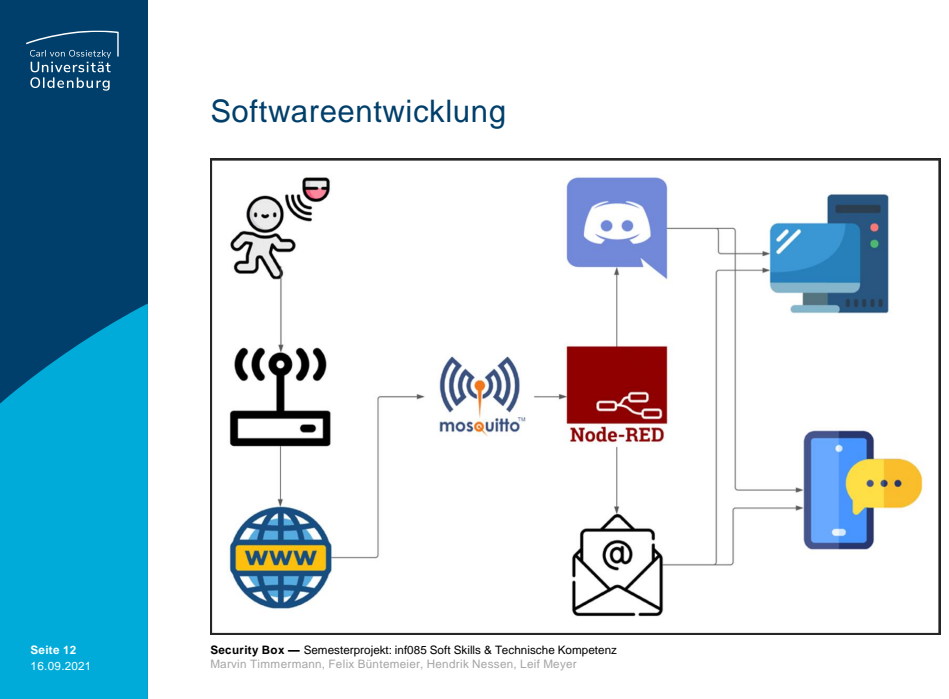
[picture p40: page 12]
Seite 12; Security Box — Semesterprojekt: inf085 Soft Skills & Technische Kompetenz

## Softwareentwicklung

Seite 13; Security Box — Semesterprojekt: inf085 Soft Skills & Technische Kompetenz

# Inbetriebnahme/Demo

Seite 14; Security Box — Semesterprojekt: inf085 Soft Skills & Technische Kompetenz

## Fazit

Seite 15; Security Box — Semesterprojekt: inf085 Soft Skills & Technische Kompetenz; ‒ Regelmäßige Meetings

‒ Angenehmes Arbeitsklima in der Gruppe

‒ Produktivität im Vordergrund

‒ Projektplan konnte eingehalten werden:

‒ Zeitpuffer und Aufgabenteilung als Risikomanagement

‒ Meilensteine wurden planmäßig erreicht

‒ Kleinere Probleme wurden schnell gelöst

‒ Hohe Zufriedenheit mit dem Projekt
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

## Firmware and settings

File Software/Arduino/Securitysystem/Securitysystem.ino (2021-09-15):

#include <ESP8266WiFi.h>
#include <PubSubClient.h>
      
const int red = D6;           // Rote led Output zu D4   
// Taster Input von D3 später in Button Klasse 
const int green = D2;         // Gruene led Output zu D2  
const int pirPin = D1;        // Sensor Input von D1
// Init von weitern Variabeln 
boolean state = true;              // True = "Home", False = "Away"  
boolean nightMode = false;         // Nightmode mit Long Press (1 Sek -> LEDs ausschalten)
int counter = 0;                   // Bei state = false, regelt timer-logik
unsigned long timeToWait = 120000; // 2min Wartezeit sobald state=false
unsigned long STime = 0;           // Für Zeitmessung
unsigned long CTime = 0;           // "  "


//----------NETWORK SETUP--------------//
//folgende Parameter anpassen. 
//--------------------------------
const char* ssid = "";
const char* password = "";
const char* mqtt_topic_subscribe1 = "MFHLSensor";
const char* mqtt_topic_publish = "MFHLSensor";
//--------------------------------

//folgende vier Parameter nicht ändern
//--------------------------------
const char* mqtt_server = "mqtt.iot.informatik.uni-oldenburg.de";
const int mqtt_port = 2883;
const char* mqtt_user = "sutk";
const char* mqtt_pw = "SoftSkills";
//--------------------------------

WiFiClient espClient;
PubSubClient client(espClient);

void setup_wifi() {

  delay(10);
  // We start by connecting to a WiFi network
  Serial.println();
  Serial.print("Connecting to ");
  Serial.println(ssid);

  WiFi.begin(ssid, password);

  while (WiFi.status() != WL_CONNECTED) {
    delay(500);
    Serial.print(".");
  }

  randomSeed(micros());

  Serial.println("");
  Serial.println("WiFi connected");
  Serial.println("IP address: ");
  Serial.println(WiFi.localIP());
  publishString("Connected");
}


void reconnect() {
  // Loop until we're reconnected
  while (!client.connected()) {
    Serial.print("Attempting MQTT connection...");

    // Create a random client ID: Client ID MUSS inviduell sein, da der MQTT Broker nicht mehrere Clients mit derselben ID bedienen kann
    String clientId = "Client-";
    clientId += String(random(0xffff), HEX);

    // Attempt to connect
    if (client.connect(clientId.c_str(), mqtt_user, mqtt_pw)) {
      Serial.println("connected");
      // Once connected, publish an announcement...
      client.subscribe(mqtt_topic_subscribe1);
 
      
    } else {
      Serial.print("failed, rc=");
      Serial.print(client.state());
      Serial.println(" try again in 5 seconds");
      // Wait 5 seconds before retrying
      delay(5000);
    }
  }
}
//----------NETWORK SETUP ENDE-------------//

//----------BUTTON CLASS-------------------//
//  https://www.hackster.io/Spivey/wemos-d1-mini-esp8266-smart-iot-button-with-messagebird-dbef7e

typedef struct Buttons {
  const byte pin = D3;                    //Button pin definiert
  const int debounce = 100;               //Delay nach Betätigung des Buttons
  const unsigned long shortPress = 100;   //Festlegung der Druckdauer (für normale Betätigungen)
  const unsigned long  longPress = 1000;  //"     " (für den Nachtmodus/LEDs Ausschalten)

  unsigned long counter = 0;      //Zählt Dauer des Drucks        
  bool previousState = HIGH;      //Vorheriger Zustand (Button ist active-low)
  bool currentState;              //Aktueller Zustand
} Button;

//----------BUTTON CLASS ENDE-------------------//

// create a Button variable type
Button button;

//----------EXTRA METHODEN-------------------//
void handleShortPress() {           
    Serial.println("short Press"); 
    state = !state;
 }


  void handleLongPress() {
    Serial.println("Long Press"); 
    digitalWrite(green, LOW);
    digitalWrite(red, LOW);
    nightMode = !nightMode;
  
 }
 
  void publishString(String payload){               
    char payload_buff[payload.length() + 1];
    payload.toCharArray(payload_buff, payload.length() + 1);
    client.publish(mqtt_topic_publish, payload_buff);
 }

//----------EXTRA METHODEN ENDE-------------------//

//----------SETUP-------------------//
void setup() {  
 pinMode(red, OUTPUT);        // Rote LED
 pinMode(green, OUTPUT);      // Grüne LED
 pinMode(pirPin, INPUT);      // Bewegungsensor
 pinMode(button.pin, INPUT);  // Taster als Eingang setzten 
 digitalWrite(red, LOW);      // Rote LED aus
 digitalWrite(green, HIGH);   // Grüne LED an

 Serial.begin(115200);

 setup_wifi();                
 client.setServer(mqtt_server, mqtt_port);
}
//----------SETUP ENDE-------------------//


//----------LOOP METHODE-------------------//
// -- Falls "Away" Sensordaten werden wahrgenommen
// -- Falls "Home" Sensordaten werden ignoriert
// Buttonlogik von Spivey (link oben)

void loop() {

  if (!client.connected()) {        // Erkennt Verbindungsverlust
    reconnect();
  }
  client.loop();
  
//--Buttonlogik--//
button.currentState = digitalRead(button.pin);          // Erfasst Buttonzustand

  if (button.currentState != button.previousState) {    // Prüft ob aktueller Zustand mit dem voherigen Zustand nicht übereinstimmt
    delay(button.debounce);                             // Delay
    button.currentState = digitalRead(button.pin);      // Erfasst Buttonzustand erneut
    if (button.currentState == LOW) {                   // Falls Button gedrückt wird Zähler mit millis gestartet
      button.counter = millis();
    } 
    else if (button.currentState == HIGH) {            // Falls Button nicht gedrückt/losgelassen, wird aktuelle Zeit erfasst
      unsigned long currentMillis = millis();          

      if ((currentMillis - button.counter >= button.shortPress) && !(currentMillis - button.counter >= button.longPress)) {
        // Falls ein Button kurz betätigt wird
        handleShortPress();
      }
      else if ((currentMillis - button.counter >= button.longPress)) {
        // Falls ein Button länger als 1 Sekunde betätigt wird
        handleLongPress();
      }
    }
    button.previousState = button.currentState;      // Voheriger Zustand wird mit dem aktuellen überschrieben
  }
//--Ende Buttonlogik--//

//--Sensorlogik--//
    if(state == true){              // Falls "Home" Sensordaten werden ignoriert; Grüne LED leuchtet            
      counter = 0;                  // Zähler zurückgesetzt
      if(nightMode == false){
        digitalWrite(green, HIGH);
        digitalWrite(red, LOW);
      }
    }

    if(state == false){           // Falls "Away" Sensordaten werden wahrgenommen; Rote LED leuchtet
      if(nightMode == false){
        digitalWrite(green, LOW);
        digitalWrite(red, HIGH);
      }
      if(counter == 0){           // counter = 0 -> Startzeit erfasst für 2min Timer dann counter = 1
        STime = millis();
        counter = 1;  
        Serial.println("Counter = 1; Startzeit erfasst");           
      }
      if(counter == 1){          // counter = 1 -> Berechnet ob 2min überschritten. Falls ja counter = 2
        CTime = millis() - STime;     
        if (CTime >= timeToWait){
          counter = 2;
          Serial.println("Counter = 2; 2min überschritten");
         }
      }
      if(digitalRead(pirPin) == LOW && counter == 2){  //counter = 2 -> wartet bis Bewegungsensor auf Low
          counter = 3;
          Serial.println("Counter = 3 Sensor Calibration Complete");  
      }

    if (digitalRead(pirPin) == HIGH && counter == 3) {   //counter = 3 -> Erfasst Bewegungsensordaten.  
      // Falls Bewegung erfasst wird Nachricht an Node-RED gesendet (weitergeleitet auf Discord und Email)
      Serial.println("Hey I got you!!!; Counter = 4");                 
      publishString("Intrusion detected by " + String(mqtt_topic_publish) + " on ");
      counter = 4;
     } 

     if (digitalRead(pirPin) == LOW && counter == 4){ //counter = 4 -> Falls keine weitere Bewegung erkannt, wird Zähler zurückgesetzt
      counter = 0;
     }
  }
//--Ende Sensorlogik--//
}
//----------ENDE LOOP METHODE-------------------//

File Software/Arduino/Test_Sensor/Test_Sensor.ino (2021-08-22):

             
const int pirPin = D1; 


void setup() {  //Nodered setup 
 pinMode(pirPin, INPUT); 

 Serial.begin(115200);
 
}

void loop(){
  
 if (digitalRead(pirPin) == HIGH) {                // if motion detected
   Serial.println("Hey I got you!!!"); //Send notification
   delay(1000);
  } 
 else {
   Serial.println("Where u at?!!!");   // turn LED OFF if we have no motion
   delay(1000);
  }
 } 

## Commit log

2021-07-27 Add files via upload
    https://www.thingiverse.com/thing:1673521/files
    Kann man verwenden um den Deckel vom Bewegungsensor zu optimieren
    [lid_PIR.stl]
2021-07-28 Add files via upload
    Überarbeiteter Deckel
    [Security_Box_V1_Deckel_V2.stl]
2021-07-28 Add files via upload
    Überarbeitete Position der Löcher im Deckel
    [Security_Box_Deckel_V2.stl]
2021-08-03 Erste Version Bewwegungssensor Arduino
2021-08-13 Zweite Version
    - NodeRED und Wifi hinzugefuegt aus den Uebungen
    - Button als Interruptpin deklariert
    - Kommentare hinzugefuegt
2021-08-17 Maße angepasst, Gehäuse modelliert
    [Security_Box_Deckel_V2.stl, Security_Box_Körper_V1.stl]
2021-08-19 Dritte Version Bewegungssensor.ino
    Neue Variablen angelegt um Zeiterfassung zu ermöglichen. Durch die Variable "counter" können wir die Wartezeit von 2 Minuten steuern, so dass nicht bei jeder Bewegung wiederholt für 2 Minuten gewarte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
2021-08-19 New Folder um Bearbeitung von Arduino Datei zu vereinfachen
2021-08-19 Switch Folder for easier Access
2021-08-21 Button Modell, KoerperV2 mit reduzierte Hoehe, Word Dokument mit Notizen
    [Security_Box_Button_V1.stl, Security_Box_Button_V2.stl, Security_Box_Koerper_V1.stl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]
2021-08-21 Code to test basic functions, such as button presses and state changes
2021-08-21 Probleme mit dem Interrupt wurden gelöst. Die Publish-Funktion konnte erfolgreich umgesetzt werden. Der Timer funktioniert und lässt State-Switch zu. LED´s schalten ordnungsgemäß um.
    Für Button-Klasse wurde folgende Quelle verwendet
    https://www.hackster.io/Spivey/wemos-d1-mini-esp8266-smart-iot-button-with-messagebird-dbef7e
    [Test_V1.ino]
2021-08-22 Create Test_Sensor.ino
    Allows Users to test the function of their PIR Sensor
2021-08-24 Create HandbuchV1
    Erste Version des Handbuchs. Die Installation des Benachrichtigungssystem muss noch verfeinert werden. Hier ist noch nicht klar wie wir dem Nutzer Zugang zu Email und Discord ermöglichen. Bilder und 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
2021-08-26 Beschreibung der 3D-Modellierung hinzugefügt
2021-08-27 Bilder des Modells bearbeitet und Beschreibung ergänzt.
2021-08-27 Hardware-Entwicklung ergänzt
    Es wurde die Hardware-Entwicklung des Projektes zur Projektdokumentation ergänzt
2021-08-30 Add files via upload
    Grafik zur Erläuterung des Systems. Schnittstellen sind eingebunden.
2021-08-31 Create Zustandsdiagramm.png
    Zustandsdiagramm der Softwareprogrammierung
2021-08-31 Update Zustandsdiagramm.png
    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
2021-09-04 Create Softwareentwicklung.docx
    Dokumentation der Softwareentwicklung. Gliederung und Formatierungen wurden noch nicht vorgenommen
2021-09-08 überarbeitet und ergänzt
2021-09-08 Software Entwicklung Update
    Es wurden Abbildungen zum Code sowie Discord und Node Red hinzugefügt. Button-Class/Logik von Spivey wurde weitererklärt.
2021-09-15 Update Securitysystem.ino
    Change red Pin to fix hardware issue and internal led conflict.
    add a counter instance between counter = 2 and counter = 3 in order to ignore first warning. First warning is possibly saved in between and not an up to date reading of the sensor
    [Securitysystem.ino]
